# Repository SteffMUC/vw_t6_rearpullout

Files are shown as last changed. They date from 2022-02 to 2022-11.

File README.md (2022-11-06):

# Get dedicated 12V car plug on rear pullout on a VW T6
Complementing rear pullout of bus-boxx with cable chain plus Neutrik connector

## Final assembly cable chain

<p float="left">
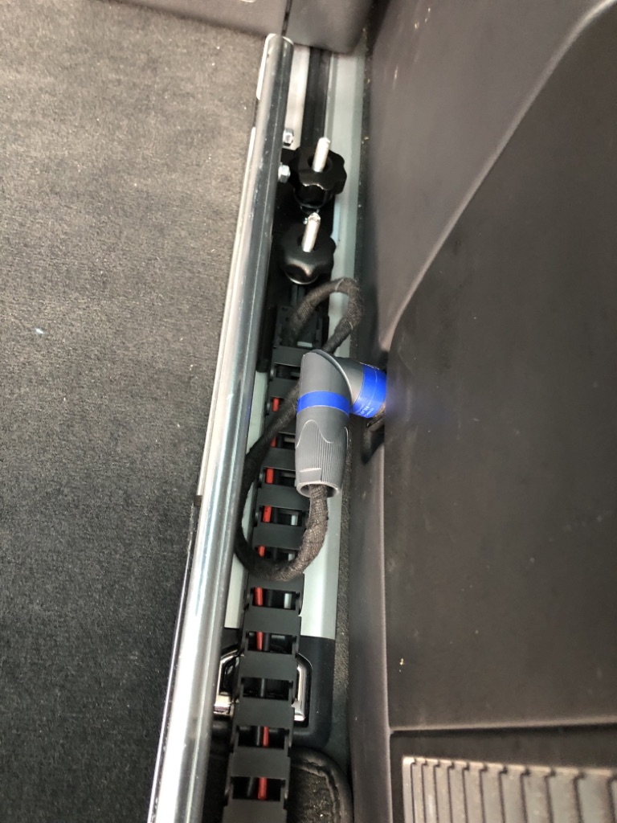
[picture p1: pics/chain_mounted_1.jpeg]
Final Assembly Part1
  
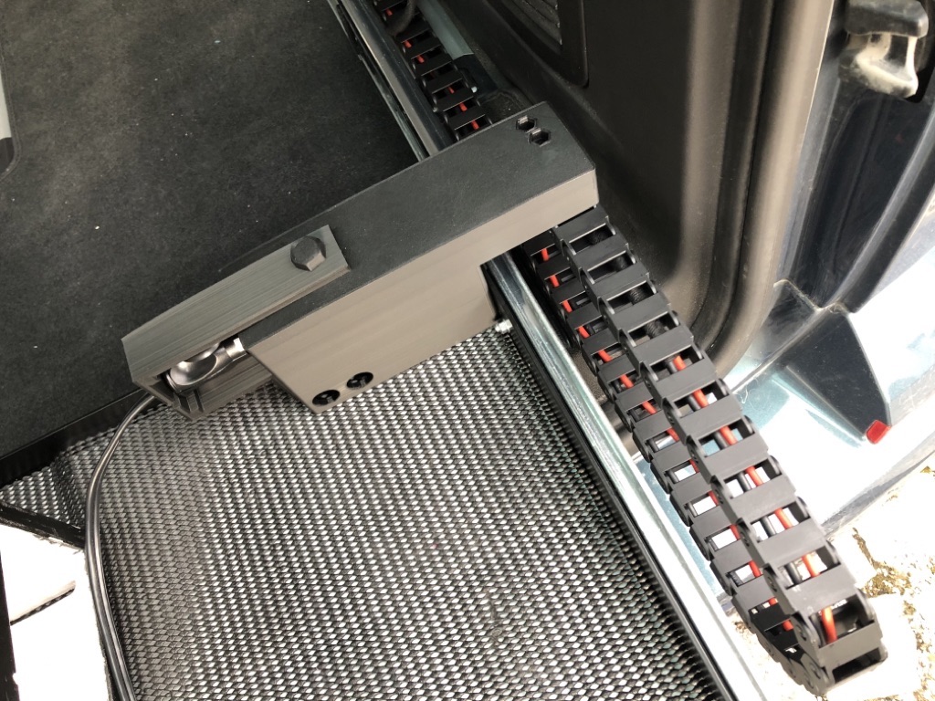
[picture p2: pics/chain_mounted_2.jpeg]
Final Assembly Part2
  
</p>

## Replacing 12V car plug by neutrik jack

Replacing the orginal 12V car plug by a neutrik jack. Connecting with cable chain to rear pull out to protect cables.

<p float="left">
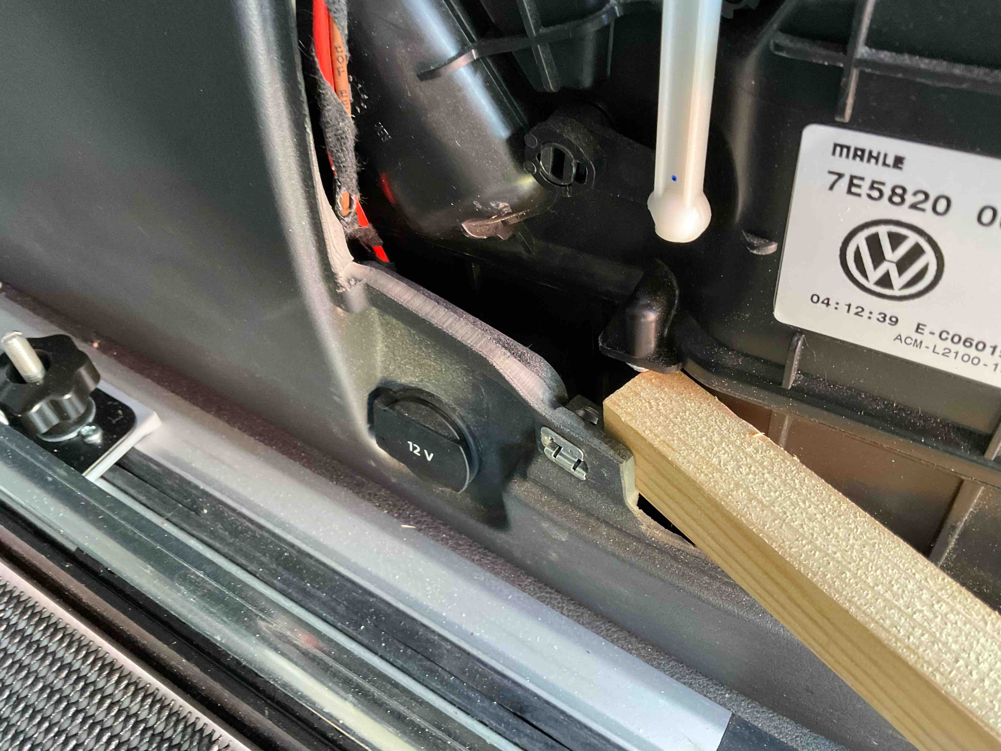
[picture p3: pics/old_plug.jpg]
Old plug
  
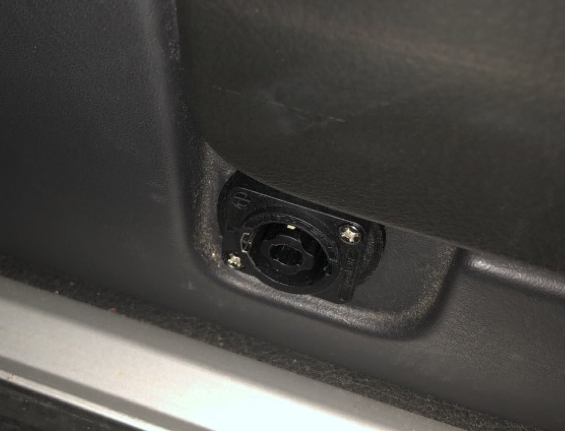
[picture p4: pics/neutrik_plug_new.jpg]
Neutrik plug
  
</p>

## Assembly instructions:

* Print all stl´s referenced in section printing instructions
* For 12V cables 2.5mm2 cables have been used. For the Neutrik plug cable terminators ([Wire End Ferrule Pliers](https://www.amazon.de/Crimpzangen-Aderendh%C3%BClsen-Preciva-Aderendh%C3%BClsenzange-st%C3%BCck/dp/B086BV38XS))have been used. All relevant parts have been protected with [Heat Shrink Tubes](https://smile.amazon.de/gp/product/B0778D22WM). For the cables 1+ and 1- have been used respectively.
* For the [Neutrik Jack](https://www.amazon.de/Neutrik-NL4MP-Speakon-Einbaubuchse/dp/B004BR2YFW/) the parts [Nut for Neutrik Adapter](https://github.com/SteffMUC/vw_t6_rearpullout/blob/main/vw_t6_car_plug_adapter_neutrik_nut.stl) and [Screw for Neutrik Adapter](https://github.com/SteffMUC/vw_t6_rearpullout/blob/main/vw_t6_carplug_neutrik_adapter_screw.stl) have to be mounted to the [Neutrik Adapter](https://github.com/SteffMUC/vw_t6_rearpullout/blob/main/vw_t6_carplug_neutrik_adapter.stl)
* The [Cable Chain](https://www.amazon.de/dp/B07S6LW7BK/) has been mounted to the [Adapter Multirail](https://github.com/SteffMUC/vw_t6_rearpullout/blob/main/vw_t6_cablechain_multivanrail_adapter.stl) with two M3 screws (taken from the set [Stainless Steel Screw Kit](https://amazon.de/gp/product/B07PFCRMKR/), protected by [Screw Lock](https://www.amazon.de/-/en/gp/product/B00295K0IQ/)
* The other end of the [Cable Chain](https://www.amazon.de/dp/B07S6LW7BK/) has been mounted to the [Rear pullout platform](https://github.com/SteffMUC/vw_t6_rearpullout/blob/main/vw_t6_cablechain_carplug_rearpullout_adapter.stl)
* If necessary the 12V plug itself can be protected against sliding out by [Screws for safety holder](https://github.com/SteffMUC/vw_t6_rearpullout/blob/main/vw_t6_cablechain_carplug_rearpullout_screws.stl) plus [Safety holder](https://github.com/SteffMUC/vw_t6_rearpullout/blob/main/vw_t6_cablechain_carplug_safety_holder_rearpullout_adapter_.stl)

<p float="left">
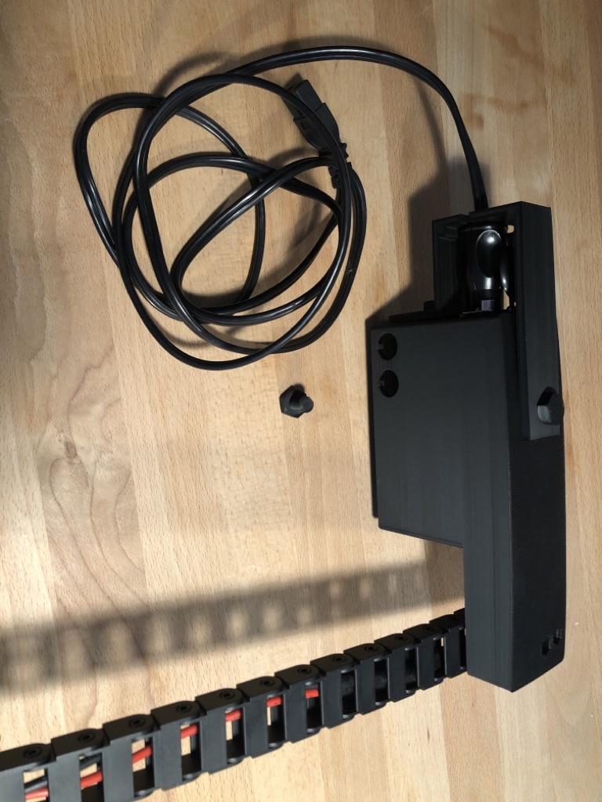
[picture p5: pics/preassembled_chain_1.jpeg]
Pre Assembly Part1
  
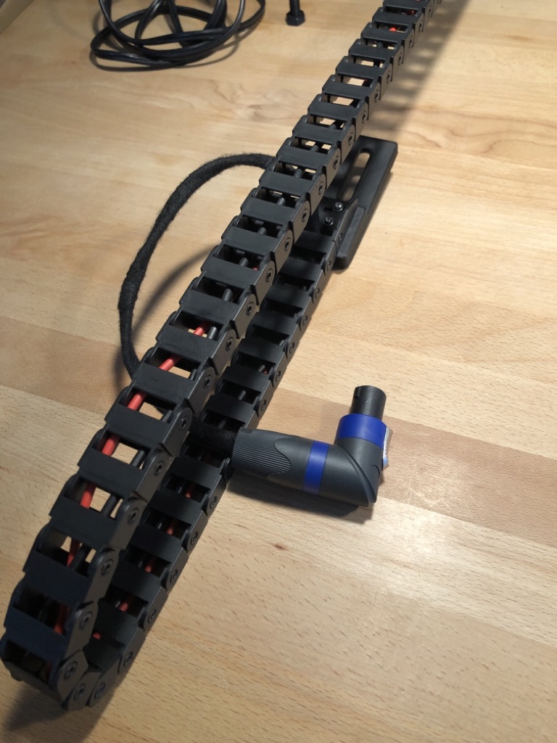
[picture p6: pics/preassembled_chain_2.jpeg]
Pre Assembly Part2
  
</p>

## Printing instructions:

### Neutrik Adapter:
[Nut for Neutrik Adapter](https://github.com/SteffMUC/vw_t6_rearpullout/blob/main/vw_t6_car_plug_adapter_neutrik_nut.stl): Printed with Ender3 Super Fine Quality 0.12mm, 90% Infill, No support

[Screw for Neutrik Adapter](https://github.com/SteffMUC/vw_t6_rearpullout/blob/main/vw_t6_carplug_neutrik_adapter_screw.stl): Printed with Ender3 Super Fine Quality 0.12mm, 90% Infill, No support

[Neutrik Adapter](https://github.com/SteffMUC/vw_t6_rearpullout/blob/main/vw_t6_carplug_neutrik_adapter.stl): Printed with Ender3 Super Fine Quality 0.12mm, 90% Infill, Support only with touching plate

### Adapter Cablechain to Multivan rail:
[Adapter Multirail](https://github.com/SteffMUC/vw_t6_rearpullout/blob/main/vw_t6_cablechain_multivanrail_adapter.stl): Printed with Ender3 Super Fine Quality 0.12mm, 90% Infill, No support

### Mounting platform on rear pullout:
[Safety holder](https://github.com/SteffMUC/vw_t6_rearpullout/blob/main/vw_t6_cablechain_carplug_safety_holder_rearpullout_adapter_.stl): Printed with Ender3 Super Fine Quality 0.12mm, 90% Infill, No support

[Screws for safety holder](https://github.com/SteffMUC/vw_t6_rearpullout/blob/main/vw_t6_cablechain_carplug_rearpullout_screws.stl): Printed with Ender3 Super Fine Quality 0.12mm, 90% Infill, No support

[Rear pullout platform](https://github.com/SteffMUC/vw_t6_rearpullout/blob/main/vw_t6_cablechain_carplug_rearpullout_adapter.stl): Printed with Ender3 Standard Quality 0.2mm, 20% Infill, No support

## Links for ordering parts:

[Rear pullout](https://bus-boxx.de/collections/heckauszug/products/t5-t6-t6-1-heckboxx-diy-do-it-yourself-bausatz)

[Cable Chain](https://www.amazon.de/dp/B07S6LW7BK/)

[Neutrik Jack](https://www.amazon.de/Neutrik-NL4MP-Speakon-Einbaubuchse/dp/B004BR2YFW/)

[Neutrik Plug](https://www.amazon.de/Neutrik-NL4FRX-Speakon-Winkelstecker-4-Pol/dp/B004BR2YDO/)

[Stainless Steel Screw Kit](https://amazon.de/gp/product/B07PFCRMKR/)

[Heat Shrink Tubing Set](https://smile.amazon.de/gp/product/B0778D22WM)

[Wire End Ferrule Pliers Set](https://www.amazon.de/Crimpzangen-Aderendh%C3%BClsen-Preciva-Aderendh%C3%BClsenzange-st%C3%BCck/dp/B086BV38XS)

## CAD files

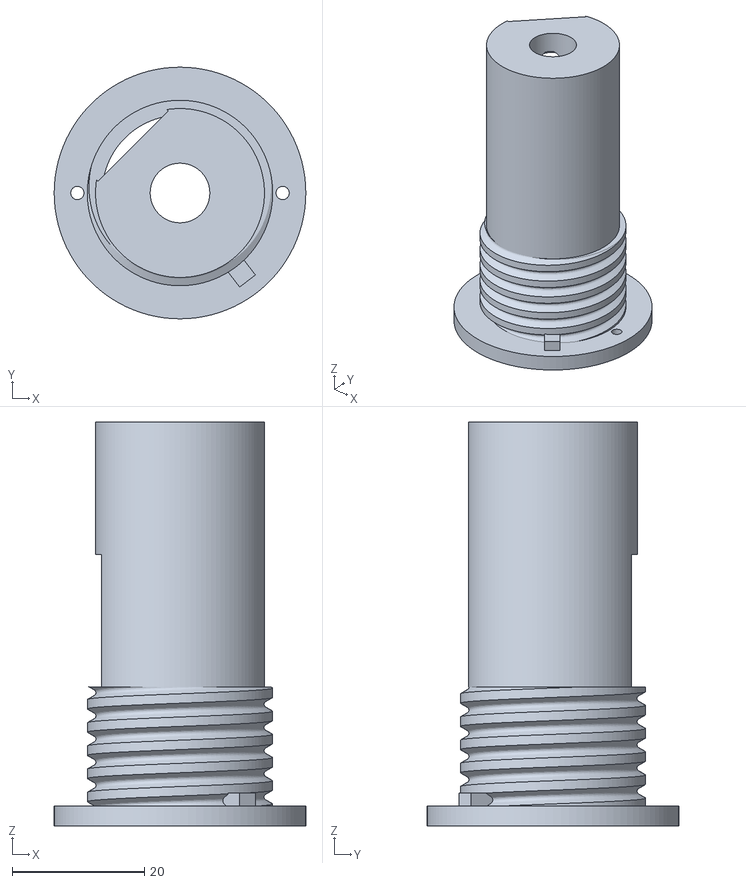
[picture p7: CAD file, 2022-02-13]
vw_t6_carplug_neutrik_adapter.stl
38.0 x 38.0 x 61.0

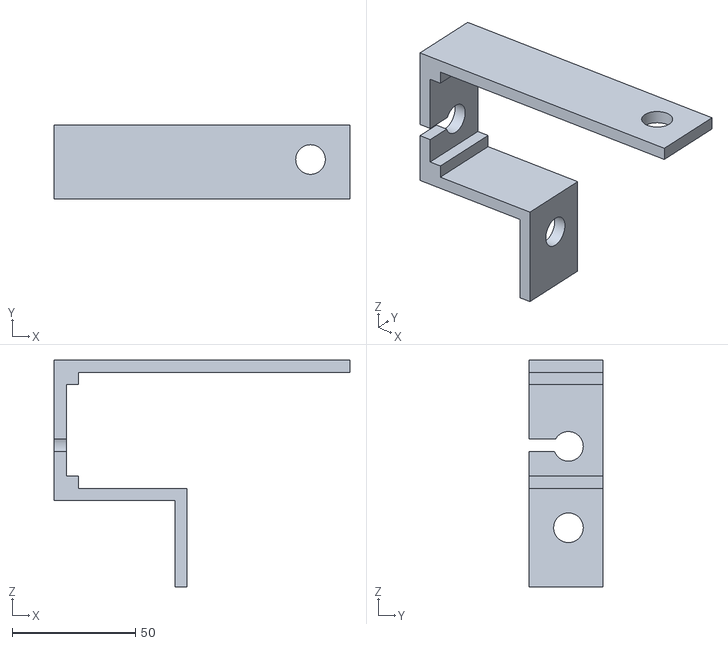
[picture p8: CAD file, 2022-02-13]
vw_t6_cablechain_carplug_safety_holder_rearpullout_adapter_.stl
120.0 x 30.0 x 92.0

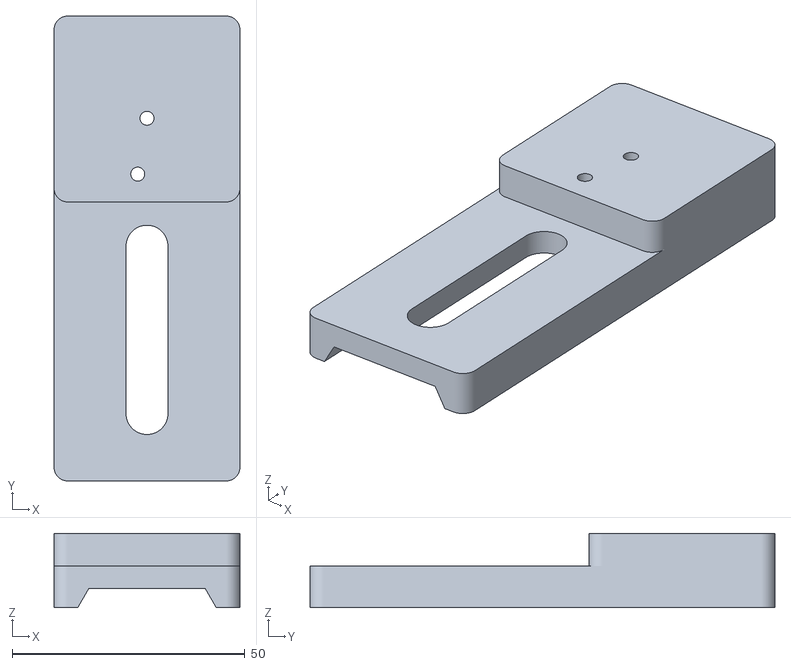
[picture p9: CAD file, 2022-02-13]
vw_t6_cablechain_multivanrail_adapter.stl
40.0 x 100.0 x 16.0

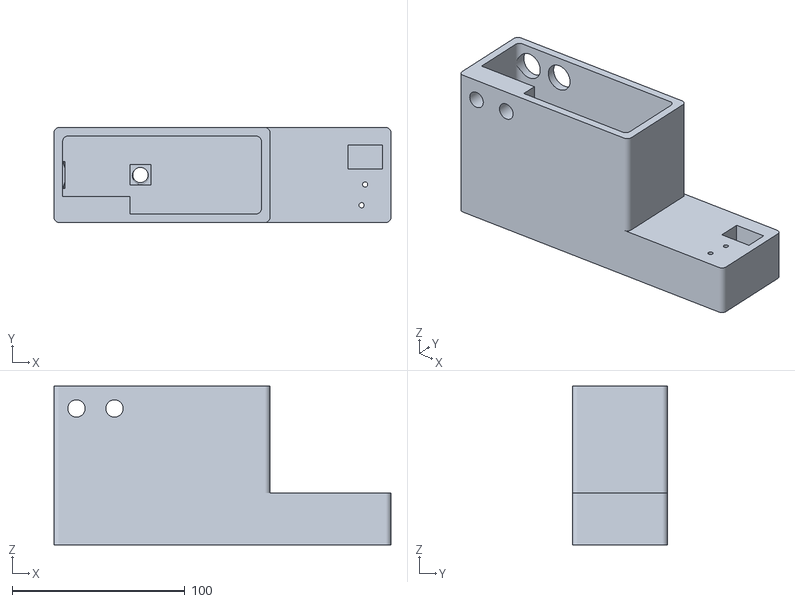
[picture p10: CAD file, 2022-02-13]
vw_t6_cablechain_carplug_rearpullout_adapter.stl
195.0 x 55.0 x 92.0

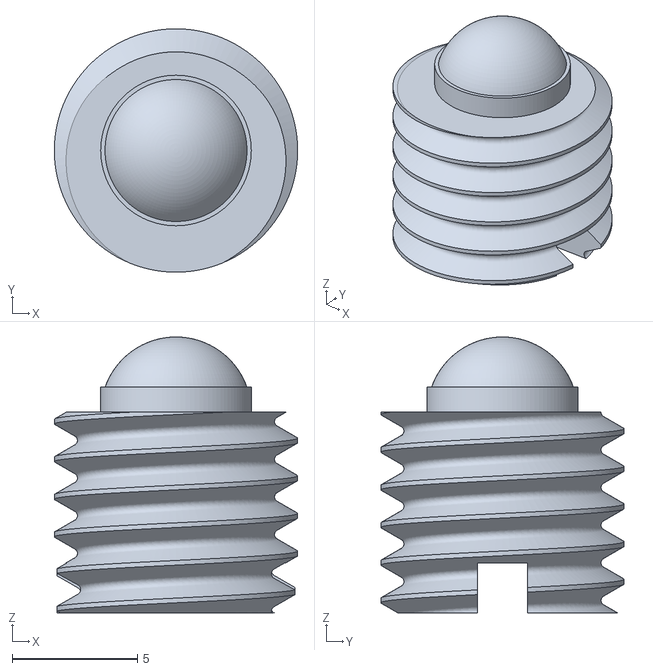
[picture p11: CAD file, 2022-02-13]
vw_t6_carplug_neutrik_adapter_screw.stl
9.70 x 9.70 x 11.0

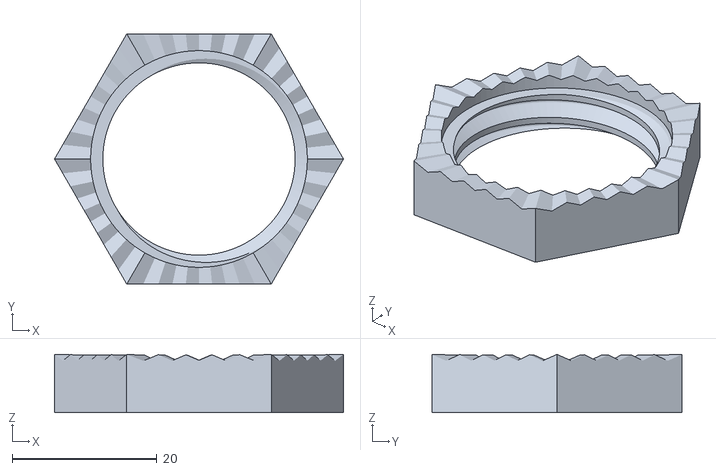
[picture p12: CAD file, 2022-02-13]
vw_t6_car_plug_adapter_neutrik_nut.stl
40.0 x 34.6 x 8.05

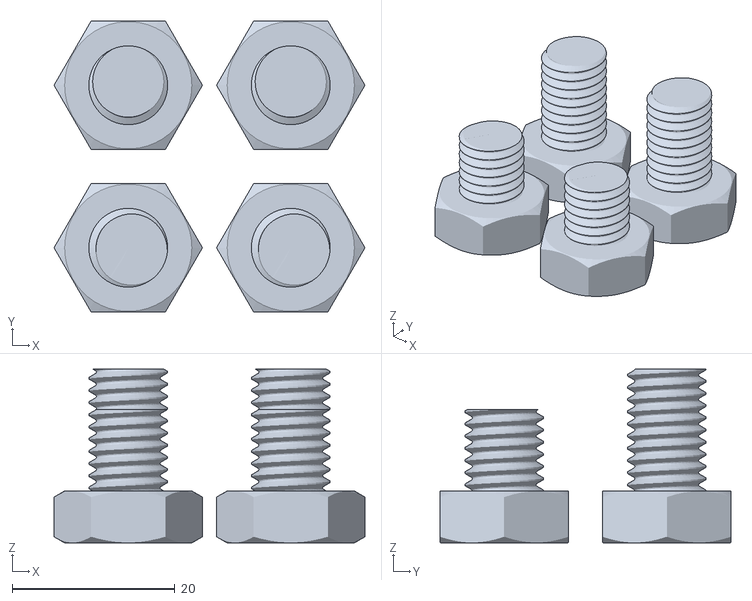
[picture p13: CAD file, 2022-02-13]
vw_t6_cablechain_carplug_rearpullout_screws.stl
38.3 x 35.8 x 21.4
